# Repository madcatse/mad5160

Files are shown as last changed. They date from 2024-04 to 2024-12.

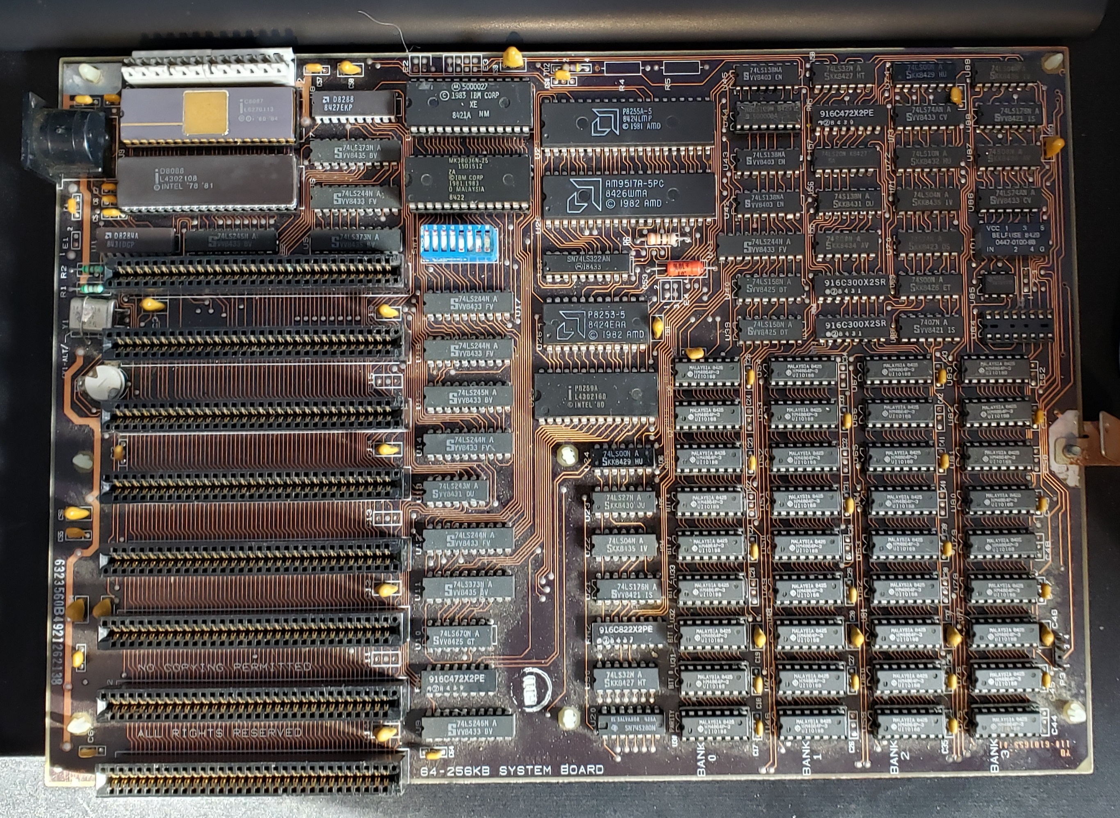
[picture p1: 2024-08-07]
Docs/Original reference photos/NC3ud42.jpeg

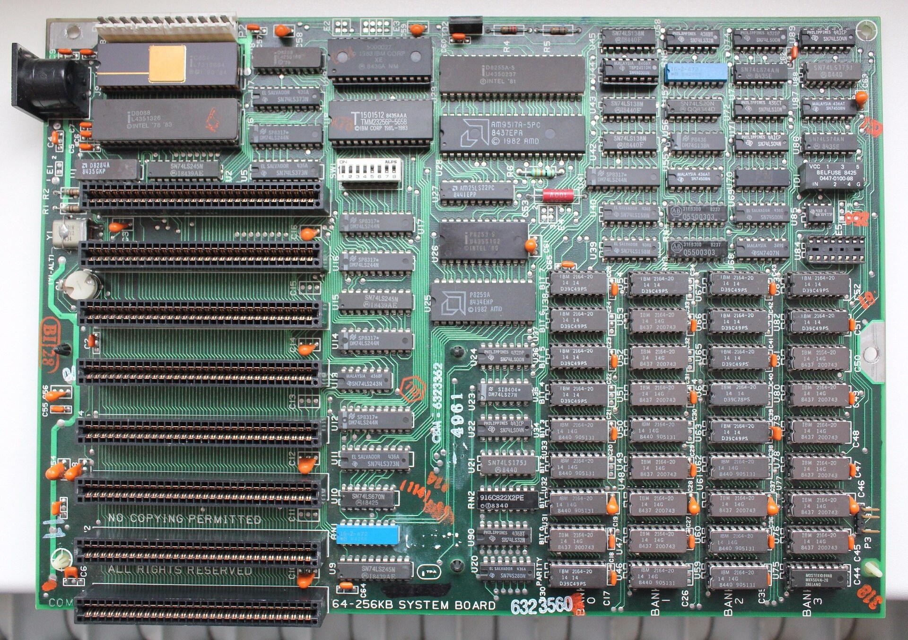
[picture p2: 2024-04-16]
Docs/Original reference photos/ibm-5160-mb-front.jpg-5f14f8fe1d3a8259343016.jpg

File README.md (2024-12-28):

Добро пожаловать в моqй проект по созданию реплики материнской платы IBM 5160, или как её называют - PC XT. 

**Предыстория**

Как-то вечером, глядя видеоролик Adrain Digital Basement о ремонте оригинальной IBM CGA видеокарты, обратил внимание что в ролике он демонстрировал схему всей видеокарты, которую кто-то выполнил в KiCAD. И упомянул, что схема иначально взята из оригинальной документации самой IBM. У меня сразу возникла мысль - а могу ли я сделать реплику такой видеокарты, раз уже проверенная схема есть в наличии?
Быстрый поиск показал что да, такая схема доступна, а также что кто-то уже сделал реплику CGA видеокарты (проект CGA Redux). Глядя на разведенную карточку, в голову проникла мысль: если есть схема видеокарты от IBM, то наверное есть схема и от материнской платы? И да - IBM 5160 Technical Reference от Апреля 1983 года действительно содержит схему на 11 листах всей материнской платы. Ну а если есть схема - то насколько сложным будет взять её и развести? Сделать реплику. Так появился данный проект.

изображение

**Начало работ и поиск подводных камней**

Вооружившись документацией из Technical Reference я принялся за работу. Нашел и скачал всю доступную документацию на 5160, разобрал, и проанализировал. Нашел фотографии материнской платы (спасибо retroweb), с которых бралась визуальная информация по компонентам. 

изображение

Потом выписал список всех компонентов на плате, с которыми предстояло работать. В этот список попали:

*центральный процессор и микросхемы, которые составляли его обвязку (чип сет, понимаете?)

*микросхемы памяти, которыми набиралась оперативная память (от 16 килобайт до 256 килобайт)

*микросхемы логики, по большей части представленные 74LS и 74S сериями

*микросхемы ПЗУ, по счастью две обычные 27С256 EPROM

*двойной периферийный драйвер SN75477P

*PAL-чип U44

*мимикрирующие под микросхемы резисторные сборки в DIP-корпусах (RN1-RN5)

*две временные задержки TD1 и TD2

*сравнительно небольшое разнообразие резисторов и конденсаторов, а также кварцевый резонатор

*стандартные 62-пиновые слоты, DIN5-коннектор под клавиатуру и Molex коннектор питания.

**С чем не было проблем**

Меньше всего проблем принес центральный процессор и его обвязка: 
Центральный процессор 8088 (совесткий аналог КР1810ВМ88)
Математический сопроцессор 8087 (чудовищно редкий совесткий аналог КР1810ВМ88)
Программируемый DMA контроллер 8237A (совесткий аналог КР1810ВТ37А)
Программируемый таймер 8253 (совесткий аналог КР580ВИ53Д)
Программируемый интерфейс периферийных устройств 8255A (совесткий аналог КР580ВВ55А)
Программируемый контроллер прерываний 8259A (совесткий аналог КР1810ВН59А)
Генератор частоты 8284A (совесткий аналог КР1810ГФ84А)
Контроллер шины M8288 (совесткий аналог КР1810ВГ88)
Все эти микросхемы сравнительно легкодоступны и их приобретение и проверка не составила никакого труда.

Микросхемы памяти также представляют собой совершенно стандартные 4164/41256 и также не вызывают проблем с их приобретением и проверкой.

То же самое касается и микросхем логики - 74 серия и её советские клоны достаточно распространены, легко приобретаются и проверяются. Неприятность в общем разнообразии микросхем. Для сборки Вам потребуются: 
7407.

74LS00,
74LS04,
74LS04,
74LS10,
74LS20,
74LS27,
74LS32,
74LS138,
74LS158,
74LS175,
74LS243,
74LS244,
74LS245,
74LS322,
74LS373,
74LS670.

74S00,
74S08,
74S74,
74S280.

Часть совершенно свободно находится на aliexpress, часть есть там же, но поддельная, часть найти будет сложно, особенно S-чипы. Но это реализуемо.

Двойной периферийный драйвер _SN75477P_ не относится к 74ой серии, но также легко доступен.

Пассивные компоненты, кварцевый резонатор, подстроеный конденсатор, слоты ISA и коннектор DIN5 для подключения клавиатуры также совершенно стандартные. 

**Проблемы**

Все это касалось комплектующих, с которыми никаких принципиальных проблем не было. К сожалению, это не все компоненты на плате. Есть часть, с которыми проблемы были, и которые пришлось решать.

**PAL 82S129N (U44)**

Злосчастная U44, на месте которой располагается PAL-чип 82S129N, программируемая логическая микросхема декодера памяти. 

изображение

Обширный поиск показал отсутствие легкодоступного дампа содержимого данной микросхемы. Однако с давных времен (декабрь 1989 года!) существует мод, 1megXT, который позволяет поставить на старые 5160-материснкие платы до 1 мегабайта памяти, и заключается в замене вышеуказанной 82S129N на GAL16V8 с хорошо задокументированной зашивкой, плюс установке одной дополнительной микросхемы. Установка такого мода мало того что решает проблему с отсутствием зашивки, так ещё и позволяет учетвертить доступный объем оперативной памяти! Хоть я и хотел поиграться с PC с 16кб памяти (минимально возмомжный объем), но как вышло так вышло. 
Для реализации этого мода Вам потребуется одна микросхема GAL16V8 и зашивка для неё. Зашивка с уравнениями присутствует в каталоге firmware\GAL16V8 Там же есть ссылка на оригинальный тред на vcfed. Микросхема GAL16V8 длиннее, чем оригинальная 82S129N, поэтому установить её напрямую не получится. Установите панель на место U44, после чего посадите GAL16V8 так чтобы в панель вошли первый и последний вины, а "хвост" остался висеть в воздухе. Поднимите пины, которые не попали в сокет, и поставьте перемычку между 8 и 10 пинами (это соединит пин земли на GAL16 и пин земли сокета). 

изображение

Обратите внимание, что в моем случае я использовал **не свою замену резистороной сборки**, а **оригинальную резисторную сборку**. Так как плата была тестовая, то резисторая сборка ставилась в панель, и она будет мешать моду, не позволяя поставить его по высоте. Надо либо паять плату сборки под основание платы, без панели, либо поднимать микросхему мода несколькими панельками. Если делать без панельки под резисторную сборку, места должно хватить.
После этого мод готов к работе, останется установить джампер на E2 и на блоке SW2 третьим и четвертым переключателем задать необходимый объем оперативной памяти (подробнее см. документацию на мод в файле \firmware\1megXT.txt)

**Резисторные сборки**

IBM установил на плате пять резисторных сборок в DIP-16 корпусах. Это:

RN1, RN5 - 15 резисторов по 4.7 кОм

изображение

RN3, RN4 - 8 резисторов по 30 Ом

изображение

RN2 - 15 резисторов по 8.2 кОм

изображение

Частично такие сборки можно купить, но цены на них очень и очень негуманные. Некоторые (8 по 30) имеют неходовой номинал и представляют собой проблему. Чтобы не заморачиваться с поиском такой экзотики я создал проект "RNDip16", располагающийся в папке \supporting_prj\RNDip16
Проект представляет собой две небольшие платы, по габаритам схожими с футпринтом микросхемы в корпусе DIP-16, на которые можно установить 8 либо 15 SMD-резисторов любого номинала, в корпусе 0805. 

изображение

После пайки резисторов следует запаять пины ножек и замена резисторной сборки готова. 

изображение

Установка такой замены допускается в сокет, либо напрямую запайкой в плату. Gerber-файлы лежат в папке \supporting_prj\RNDip16\gerbers

**Линии временной задержки TD1 и TD2**

Довольно экзотические компоненты установлены под обозначениями TD1 и TD2. Данные компоненты обеспечивают контролируемую задержку сигнала и являются критичными для корректной работы компьютера. По счастью само IBM в документации от 1986ого года выбросил из схемы TD2, заменив её обычным резистором, убрав резисторы R4 и R5. Но вот TD1 осталась, как и проблемы с ней. Часто на её месте стоят компоненты от BELFUSE 0447-0100-98, либо SPRAGUE 61Z14A100. Это линия задержки на 5 выходов, каждый из которых добавляет 20нс к времени выхода сигнала. На ebay такие компоненты можно купить, однако у нас в настоящий момент это исключено. 

изображение

Поиск показал что существуют современные вариации таких задержек - DS1100Z-100 в корпусе NSOIC-8. Я создал проект time_delay, расположенный по пути \supporting_prj\time_delay ,который представляет собой крошечную плату с габаритами исходной временной задержки, на которую необходимо напаять DS1100Z-100 и пины, после чего данный компонент на 100% заменяет исходную временную задержку. 

изображение

изображение

Gerber-файлы лежат в папке \supporting_prj\time_delay\Gerbers

**Коннектор питания P8/P9**

Старый-добрый AT-коннектор питания (что, получается, неверно, так как у нас XT и этот тип коннектора должен тогда называться XT-коннектор). 

изображение

Его можно взять с донорской материнской платы, но я решил поставить современный вариант. Molex 26604060, имеет такие же габариты, но пины квадратной, а не плоской формы. 

изображение

изображение

Однако типовой AT-блок питания подключается без проблем, и нет нужды искать донора.

**BIOS**

Микросхемы биоса используются совершенно стандартные, 27C256. В одной находится сам биос, в другой - ром с IBM BASIC. Все оригинальные BIOS есть здесь: https://www.minuszerodegrees.net/bios/bios.htm
Также можно использовать различные сторонние BIOS, в частности биос от TurboXT, доступный по пути firmware\turboxt\turboxt.bin

**Ошибки в схеме**

Первая ревизия платы (версия 0.1) содержала в себе ошибку, связанную с опечаткой в оригинальной IBM документации. Для сравнения, фрагмент схемы 1983 года:

изображение

Тот же участок в схеме от 1986 года:

изображение

Из-за этого линия проверки четности на ISA-слоте была подтянута на +5 постоянно через резистор, и система ВСЕГДА при старте определяла ошибку четности. Это единственный фикс, который потребовалось сделать в схеме после того как был изготовлен, собран и испытан первый образец.

**Печатная плата**

Печатную плату я разводил используя в качестве ориентира скан платы, любезно предоставленный пользователем jafir с форума vcfed, а также остальные референсные фото. Так как оригинальная плата четырехслойная, я не имел на руках оригинальной платы, и тем более не мог сделать послойную декомпозицию платы с целью анализа проводников на внутренних слоях платы, трассировка всех проводников выполнена с нуля. Сигнальные слои - F.Cu и B.Cu. Слой In1.Cu - +5В, слой In2.Cu - земля. Линии +12В, -12В и -5В проведены по сигнальным слоям. Контур платы, координаты посадочных отверстий, некоторые посадочные места компонентов (трехвыводные конденсаторы, пленочный конденсатор, подстроечный конденсатор) взяты из открытого проекта-реплики IBM PC 5150 (PC-Retro, MTM Scientific)

**Изготовление и сборка**

Четырехслойная печатная плата без каких либо особенностей. Изготовление возможно силами китайских производителей. Gerbar-файлы для изготовления находятся по пути \gerbers

изображение

**Благодарности**

Выражаю огромное спасибо за идею, помощь в проектировании и отладке:
Adrinan Black с канала Adrian Drigital Basement за идею, а также диагностический ром для памяти, который помог локализовать проблему с Parity

jafir с форума vcfed за качественный скан материнской платы

modem7 с форума vcfed за помощь в локализации проблемы и идеи по исправлению.

**Контакты**

Связаться со мной можно в телеграме, на моем небольшом канале:
https://t.me/madcatse

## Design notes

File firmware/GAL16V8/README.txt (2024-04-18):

Here are the GAL16V8 JEDEC, EQN and LOG files for anyone who wants to duplicate this. Since you'll be putting a 20-pin DIP iinto a 16-pin socket, you'll need to connect pins 8 and 10 (it's okay to include pin 9 if that makes the job easier) on the 20 pin DIP or, if you use a stacked socket, the socket. Just plug the GAL in so that pin 1 on the GAL matches pin 1 of U44 on the 5160 planar. Stick in 4 banks of 41256s and you're good to go.

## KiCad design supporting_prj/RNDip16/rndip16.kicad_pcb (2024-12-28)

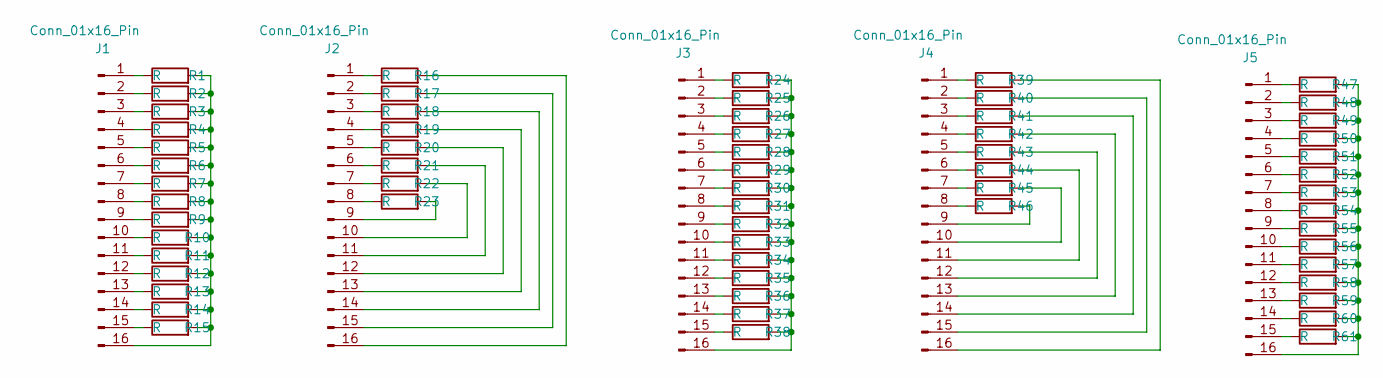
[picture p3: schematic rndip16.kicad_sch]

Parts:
J1, J2, J3, J4, J5: Conn_01x16_Pin; Dip16_package
R1, R2, R3, R4, R5, R6, R7, R8, R9, R10, R11, R12, R13, R14, R15, R16, R17, R18, R19, R20, R21, R22, R23, R24, R25, R26, R27, R28, R29, R30, R31, R32, R33, R34, R35, R36, R37, R38, R39, R40, R41, R42, R43, R44, R45, R46, R47, R48, R49, R50, R51, R52, R53, R54, R55, R56, R57, R58, R59, R60, R61: R; R_0805

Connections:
unnamed: J1.1, R1.1
unnamed: J1.2, R2.1
unnamed: J1.3, R3.1
unnamed: J1.4, R4.1
unnamed: J1.5, R5.1
unnamed: J1.6, R6.1
unnamed: J1.7, R7.1
unnamed: J1.8, R8.1
unnamed: J1.9, R9.1
unnamed: J1.10, R10.1
unnamed: J1.11, R11.1
unnamed: J1.12, R12.1
unnamed: J1.13, R13.1
unnamed: J1.14, R14.1
unnamed: J1.15, R15.1
unnamed: J1.16, R1.2, R2.2, R3.2, R4.2, R5.2, R6.2, R7.2, R8.2, R9.2, R10.2, R11.2, R12.2, R13.2, R14.2, R15.2
unnamed: J2.1, R16.1
unnamed: J2.2, R17.1
unnamed: J2.3, R18.1
unnamed: J2.4, R19.1
unnamed: J2.5, R20.1
unnamed: J2.6, R21.1
unnamed: J2.7, R22.1
unnamed: J2.8, R23.1
unnamed: J2.9, R23.2
unnamed: J2.10, R22.2
unnamed: J2.11, R21.2
unnamed: J2.12, R20.2
unnamed: J2.13, R19.2
unnamed: J2.14, R18.2
unnamed: J2.15, R17.2
unnamed: J2.16, R16.2
unnamed: J3.1, R24.1
unnamed: J3.2, R25.1
unnamed: J3.3, R26.1
unnamed: J3.4, R27.1
unnamed: J3.5, R28.1
unnamed: J3.6, R29.1
unnamed: J3.7, R30.1
unnamed: J3.8, R31.1
unnamed: J3.9, R32.1
unnamed: J3.10, R33.1
unnamed: J3.11, R34.1
unnamed: J3.12, R35.1
unnamed: J3.13, R36.1
unnamed: J3.14, R37.1
unnamed: J3.15, R38.1
unnamed: J3.16, R24.2, R25.2, R26.2, R27.2, R28.2, R29.2, R30.2, R31.2, R32.2, R33.2, R34.2, R35.2, R36.2, R37.2, R38.2
unnamed: J4.1, R39.1
unnamed: J4.2, R40.1
unnamed: J4.3, R41.1
unnamed: J4.4, R42.1
unnamed: J4.5, R43.1
unnamed: J4.6, R44.1
unnamed: J4.7, R45.1
unnamed: J4.8, R46.1
unnamed: J4.9, R46.2
unnamed: J4.10, R45.2
unnamed: J4.11, R44.2
unnamed: J4.12, R43.2
unnamed: J4.13, R42.2
unnamed: J4.14, R41.2
unnamed: J4.15, R40.2
unnamed: J4.16, R39.2
unnamed: J5.1, R47.1
unnamed: J5.2, R48.1
unnamed: J5.3, R49.1
unnamed: J5.4, R50.1
unnamed: J5.5, R51.1
unnamed: J5.6, R52.1
unnamed: J5.7, R53.1
unnamed: J5.8, R54.1
unnamed: J5.9, R55.1
unnamed: J5.10, R56.1
unnamed: J5.11, R57.1
unnamed: J5.12, R58.1
unnamed: J5.13, R59.1
unnamed: J5.14, R60.1
unnamed: J5.15, R61.1
unnamed: J5.16, R47.2, R48.2, R49.2, R50.2, R51.2, R52.2, R53.2, R54.2, R55.2, R56.2, R57.2, R58.2, R59.2, R60.2, R61.2

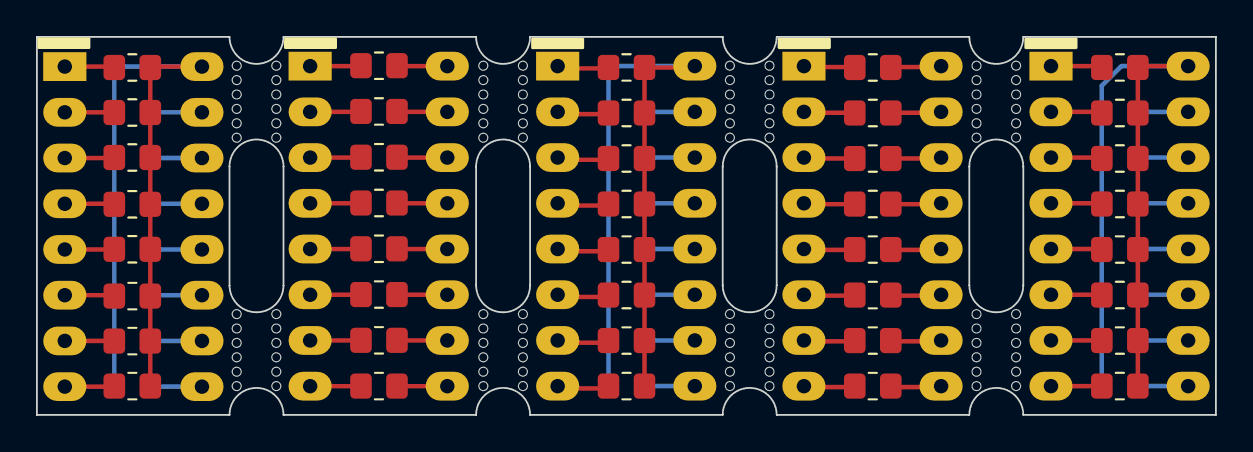
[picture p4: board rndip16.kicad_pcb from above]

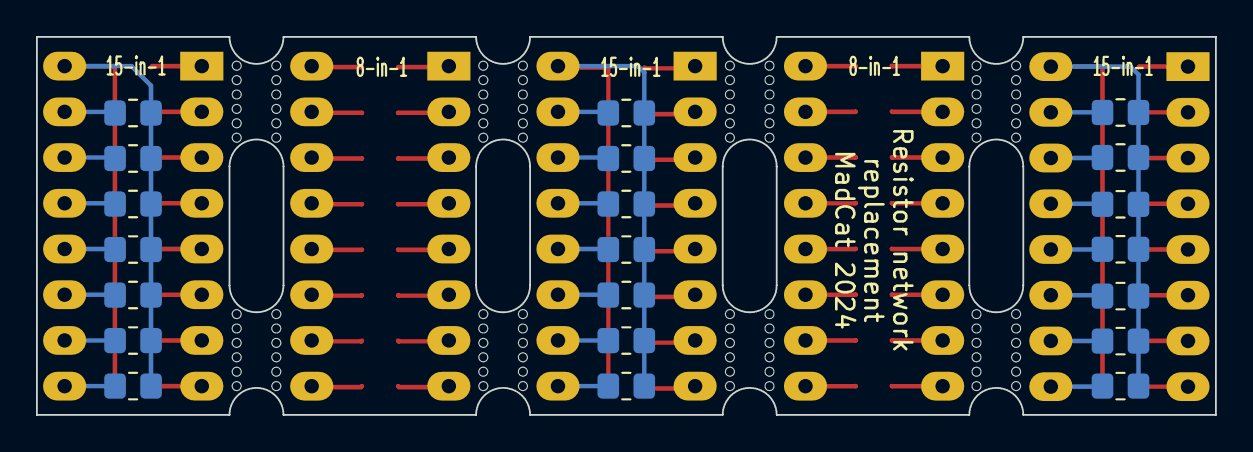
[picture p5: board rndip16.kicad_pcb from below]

Board: 2 copper layers, 65.5 x 21.0 mm, 74 parts (21 on the bottom side), 80 nets.

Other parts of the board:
mouse-bite-2.54mm-slot_13, mouse-bite-2.54mm-slot_13#2, mouse-bite-2.54mm-slot_13#3, mouse-bite-2.54mm-slot_13#4, mouse-bite-2.54mm-slot_13#5, mouse-bite-2.54mm-slot_13#6, mouse-bite-2.54mm-slot_13#7, mouse-bite-2.54mm-slot_13#8: VAL**; mouse_bite

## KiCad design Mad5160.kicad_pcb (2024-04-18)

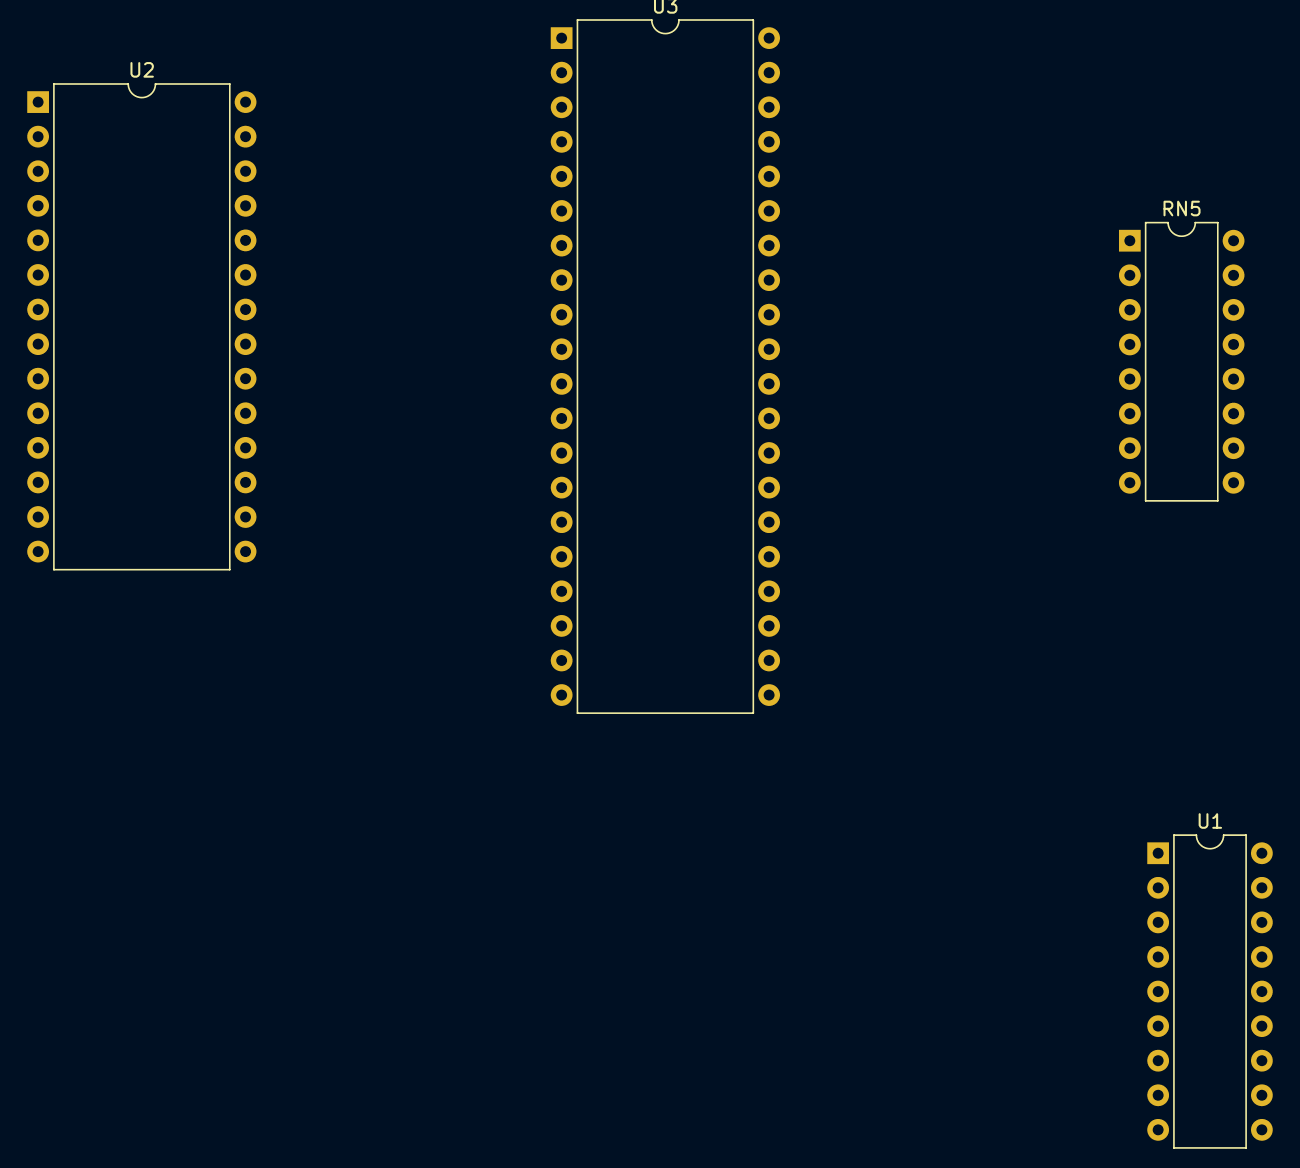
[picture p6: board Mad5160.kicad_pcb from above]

Board: 2 copper layers, 4 parts (0 on the bottom side), 10 nets, no tracks yet.

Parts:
RN5: 4.7K; DIP-16_W7.62mm
U1: 8284A; DIP-18_W7.62mm
U2: 8259A; DIP-28_W15.24mm
U3: 8088; DIP-40_W15.24mm

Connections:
+5V: RN5.16, U2.28 (Vcc)
unnamed: RN5.7, U2.16 (~SP/~EN)
XD0: U2.11 (D0), U3.19 (CLK)
XD1: U2.10 (D1), U3.21 (RESET)
XD2: U2.9 (D2), U3.17 (NMI)
XD3: U2.8 (D3), U3.16 (AD0)
XD4: U2.7 (D4), U3.15 (AD1)
XD5: U2.6 (D5), U3.14 (AD2)
XD6: U2.5 (D6), U3.13 (AD3)
XD7: U2.4 (D7), U3.12 (AD4)

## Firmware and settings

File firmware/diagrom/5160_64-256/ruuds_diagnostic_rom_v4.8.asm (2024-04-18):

;
; 	          Diagnostic ROM for IBM-PC/XT and compatibles
;
;		   Written by Ruud Baltissen - up to version V3
;
;			from version 3.0 on: modem7 at the Vintage Computer Federation Forums
;
;
;   To be compiled with NASM 2.11 or higher. Not tested with older versions.
;
;
; Notes:
; -	This ROM can be used to diagnose the IBM-PC, IBM-XT and compatible 
;	computers.
; -	This version only supports the MDA and CGA video adapter. The reason: 
;	the EGA and VGA cards need to be initialized by their own ROMs and I'm
;	sure that they run subroutines and therefore need RAM for the stack. 
;	The Landmark diagnostic ROM supports EGA by using its own routines but
;	1) IMHO that needs more effort than it is worth the trouble and time
;	and 2) and EGA monitors are rare nowadays.
;
; -	This test simply expects that a MDA or a CGA video card is present. In
;	case both cards are present, in this version only the MDA card will be
;	used.
; -	After the checksum test the program will beep to inform the user that
;	the test is running fine so far. But if there is nothing on the screen
;	at that point, there is either something wrong with the board or the
;	video system.
; -	If the CPU is to be found bad, the test stops. Why continuing with a
;	bad processor? Remark: a bad EPROM can cause this error as well.
; -	If the checksum of the EPROM is not correct, the test stops. If I can't
;	trust the EPROM, can I trust the outcome of the following tests?
; -	If the program can't find 2 KB of good memory from 0000:0000h on, the
;	test will stop as well. The rest of the program needs RAM for the
;	interrupt vectors and subroutines. Without RAM that is not possible. 
;	I know Landmark can continue by using this ROM-Stack method but this is
;	a very labour intensive way of programming. I'm interested in repairing
;	PCs with this tool and if the memory is bad, then repair that problem
;	first before looking for possible other problems.
; -	General remark: broken glue logic and buffers can cause errors that are
;	interpreted wrong by this diagnostic ROM or errors that won't be 
;	detected at all. For example: a broken data buffer can cause that 
;	nothing shows up at the screen althought the video card itself is fine.


; Versions
;	This is a project I do just for fun. So I had no intention to keep
;	track of any change I made. In case of a major change I will save a
;	dated copy for myself but that was all.
; V2:
;	But in october 2022 I decided for an important change: use the not-used
;	video RAM as stack. The advantage: the whole is MUCH more easier to 
;	program. The minor disadvantage: only MDA and CGA video cards are supported.


; Disclaimer
; -	All names with a copyright are acknowledged.
; -	Some information is derived from deduction after reading a lot of
;	documents and can be unreliable due to the lack of real proof.
; -	If you use this source code and the resulting binary, then it is on
;	your own account. I cannot be held responsible for blowing up your
;	computer, mother-in-law or whatever; it will always be your own fault.
;	USING THIS SOURCE CODE AND ITS BINARY IS COMPLETELY AT YOUR OWN RISK !!!
; -	I'm a Dutchman and English is not my native language. So you can expect
;	to find several linguistic mistakes.



;-------------------------------------------------------------------------------
; I/O port information
;-------------------------------------------------------------------------------
DMA8237_0_ar	equ	0		; channel 0 address register
DMA8237_0_wc	equ	1		; channel 0 word count
DMA8237_1_ar	equ	2		; channel 1 address register
DMA8237_1_wc	equ	3		; channel 1 word count
DMA8237_2_ar	equ	4		; channel 2 address register
DMA8237_2_wc	equ	5		; channel 2 word count
DMA8237_3_ar	equ	6		; channel 3 address register
DMA8237_3_wc	equ	7		; channel 3 word count
DMA8237_scr	equ	8		; status/command register
DMA8237_req	equ	9		; Request register
DMA8237_mask	equ	0Ah		; Mask register
DMA8237_mode	equ	0Bh		; Mode register
DMA8237_cmlff	equ	0Ch		; Clear MSB/LSB flip flop
DMA8237_mc	equ	0Dh		; Master clear

; Programmable Interrupt Controller
PIC8259_cmd	equ	20h		; command port
PIC8259_imr	equ	21h		; interrupt mask register

; Programmable Interval Timer
PIT8253_0	equ	40h		; channel 0
PIT8253_1	equ	41h		; channel 1
PIT8253_2	equ	42h		; channel 2
PIT8253_ctrl	equ	43h		; control

; Programmable Peripheral Interface 8255
PPI8255_A	equ	60h		; port A
PPI8255_B	equ	61h		; port B
PPI8255_C	equ	62h		; port C
PPI8255_ctrl	equ	63h		; control

DebugIO		equ	80h

; DMA page register
DmaPageRegCh2	equ	81h
DmaPageRegCh3	equ	82h
DmaPageRegCh1	equ	83h

NmiCtrlPort	equ	0A0h

LPT1		equ	378h
LPT2		equ	278h
LPT3		equ	3BCh		; Found on most MDA cards.

COM1_tx_rx_dll	equ	3F8h		; Tx/Rx or Divisor Latch LS (DLL)
COM1_ier_dlm	equ	3F9h		; Interrupt Enable Register (IER) or Divisor Latch MS (DLM)
COM1_iir	equ	3FAh		; Interrupt Ident Register (IIR)
COM1_lcr	equ	3FBh		; Line Control Register (LCR)
COM1_mcr	equ	3FCh		; MODEM Control Register (MCR)
COM1_lsr	equ	3FDh		; Line Status Register (LSR)

MDA_index	equ	3B4h		; 6845 Index Register
MDA_data	equ	3B5h		; 6845 Data Register
MDA_ctrl	equ	3B8h		; CRT Control Port 1

CGA_index	equ	3D4h		; 6845 Index Register
CGA_data	equ	3D5h		; 6845 Data Register
CGA_ctrl	equ	3D8h		; Mode Control Register
CGA_pal		equ	3D9h		; Color Select Register

FdcDor		equ	3F2h		; Digital Output Register (DOR)
FdcMsr		equ	3F4h		; Main Status Register (MSR)
FdcCdr0		equ	3F5h		; Command/Data Register 0

SegMdaRam	equ	0B000h
SegCgaRam	equ	0B800h

OurSpAddress	equ	4094		; What we will set the stack pointer to.

BrCornerOffset	equ	3940		; Screen offset at bottom right corner where a segment:offset gets displayed.

START		equ	0E000h		; Code starts at offset E000h.


;-------------------------------------------------------------------------------
; Variables stored in low motherboard RAM (after that RAM has been FULLY tested).
;-------------------------------------------------------------------------------
IntIsrRecord	equ	0400h		; Address = 0000:0400 - Where the ISR record is stored.
KybTestResult	equ	0401h		; Address = 0000:0401 - Where the result of the keyboard test is stored.
FdcResetCount	equ	0402h		; Address = 0000:0402 - Used by the FDC reset subroutine.
FloppyReadCount	equ	0403h		; Address = 0000:0403 - Used by the 'read a floppy' test.
NmiFlag		equ	0404h		; Address = 0000:0404 - Normally 0. NMI handler will set this to 1.
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

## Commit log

2024-04-16 Initial upload
    [Mad5160.kicad_pcb, Mad5160.kicad_sch, ist1.kicad_sch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]
2024-04-16 Update 16.04.2024
    Two datasheets added (8087 and 8288), library updated.
    [list1.kicad_sch]
2024-04-18 Small update 18.04.2024
    [list1.kicad_sch]
2024-04-18 First PCB draw
    [list1.kicad_sch]
2024-04-19 Update 19/04
    [list1.kicad_sch]
2024-04-19 Adlib project import
    [Adlib-2024-04-19-14-29-44.sch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]
2024-04-19 First list finished
    [list1.kicad_sch]
2024-04-19 Sheet 2
    [Mad5160.kicad_sch, Sheet2.kicad_sch, list1.kicad_sch]
2024-04-19 Adlib part
    [Adlib.kicad_pcb, Adlib.kicad_sch]
2024-04-20 Sheet 2 finished
    [Mad5160.kicad_sch, Sheet2.kicad_sch, sheet1.kicad_sch]
2024-04-20 3d fixes
    [Adlib.kicad_pcb]
2024-04-22 Working on Sheet3
    [Mad5160.kicad_sch, Sheet2.kicad_sch, sheet3.kicad_sch]
2024-04-23 Sheet 3 finished
    [Sheet2.kicad_sch, sheet1.kicad_sch, sheet3.kicad_sch]
2024-04-23 Sheet 4 finished
    [Mad5160.kicad_sch, Sheet2.kicad_sch, sheet1.kicad_sch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]
2024-04-24 Sheet 5 symbols
    [Mad5160.kicad_sch, sheet1.kicad_sch, sheet3.kicad_sch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]
2024-04-25 Sheet 5 finished
    [sheet1.kicad_sch, sheet5.kicad_sch]
2024-04-26 Working on sheet 6
    [Mad5160.kicad_sch, Sheet2.kicad_sch, sheet1.kicad_sch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]
2024-04-27 Sheet 7
    [Mad5160.kicad_sch, sheet3.kicad_sch, sheet6.kicad_sch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]
2024-04-27 Sheet 8 finished
    [Mad5160.kicad_sch, Sheet2.kicad_sch, sheet7.kicad_sch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]
2024-04-28 Sheet 9 finished, almost there
    [Mad5160.kicad_sch, Sheet2.kicad_sch, sheet1.kicad_sch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]
2024-04-29 Sheet 10 done
    [Sheet2.kicad_sch, sheet1.kicad_sch, sheet10.kicad_sch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]
2024-04-29 At connector
    [sheet10.kicad_sch]
2024-05-01 Update 010502024
    [Sheet2.kicad_sch, sheet1.kicad_sch, sheet10.kicad_sch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]
2024-05-02 Begin tracing
    [sheet1.kicad_sch, sheet10.kicad_sch, sheet8.kicad_sch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]
2024-05-03 Update 03/05/2024
    [Adlib-2024-04-19-14-29-44.sch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]
2024-05-09 Tracing for version 1.0 finished
    [Adlib-B.Cu.gbl, Adlib-B.Mask.gbs, Adlib-B.SilkS.gbo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]
2024-05-12 Tracing finished
    [Sheet2.kicad_sch, sheet1.kicad_sch, sheet10.kicad_sch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]
2024-05-19 Fixing bugs
    [Sheet2.kicad_sch, sheet1.kicad_sch]
2024-05-19 Fixing, fixing...
    [Sheet2.kicad_sch, sheet1.kicad_sch, sheet10.kicad_sch]
2024-05-20 Time delay ver1
    [Adlib.kicad_pcb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]
2024-05-21 Fixing stuff
    [Sheet2.kicad_sch, sheet1.kicad_sch, sheet3.kicad_sch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]
2024-05-21 Second tracing added
    Had to retrace the whole board due to lots of changes
2024-05-29 Small update
    [mad5150.xlsx]
2024-08-07 Version 1.0 fix
    [Mad5160-B_Cu.gbr, Mad5160-B_Mask.gbr, Mad5160-B_Silkscreen.gbr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]
2024-08-07 Cleaning projects
    [Batch-Si.SDF, ist1.kicad_sch, list1.kicad_sch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]
2024-09-22 Cleaning before publishing
    Cleaning before publishing
    [Adlib-2024-04-19-14-29-44.sch, Adlib.kicad_pcb, Adlib.kicad_sch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]
2024-09-22 Gerbers updated
2024-10-23 RNDip fix
    [rndip16-B_Cu.gbr, rndip16-B_Mask.gbr, rndip16-B_Paste.gbr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]
